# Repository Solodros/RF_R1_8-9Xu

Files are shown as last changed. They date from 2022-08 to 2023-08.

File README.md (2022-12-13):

# RF_R1_8-9Xu

Open source universal PCB for the Realforce R1 family of keyboards.

## Introduction

This project is a continuation of my development of open source EC boards.

The supported layouts are the one of the Realforce R1 family of keyboards, it being ANSI, ISO or JIS.

## Technical information

- Layout size: tenkeykess (TKL)
- Compatible switches: EC switches (Topre and NIZ)
- Microcontroller: STM32F401
- Connector:
    * internal USB-C
    * original JST connector S4B-EH(LF)(SN)
    * jst connector for daughterboard
- Addressable RGB strip support
- Firmware compatibility: QMK (with VIA/VIAL support)
- Protection hardware (on all connection methods):
  * Fused
  * ESD protection

## Renders and Prototypes

### Render

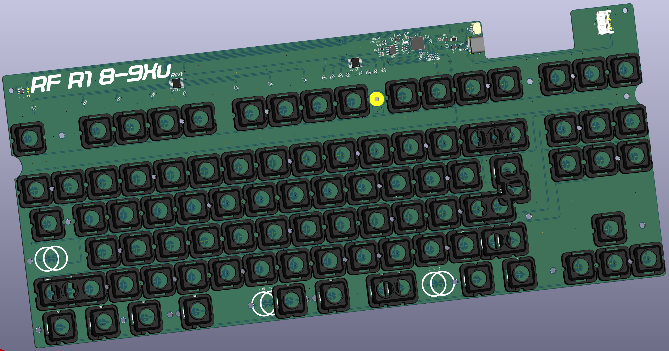
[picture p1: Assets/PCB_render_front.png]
PCB Front Render


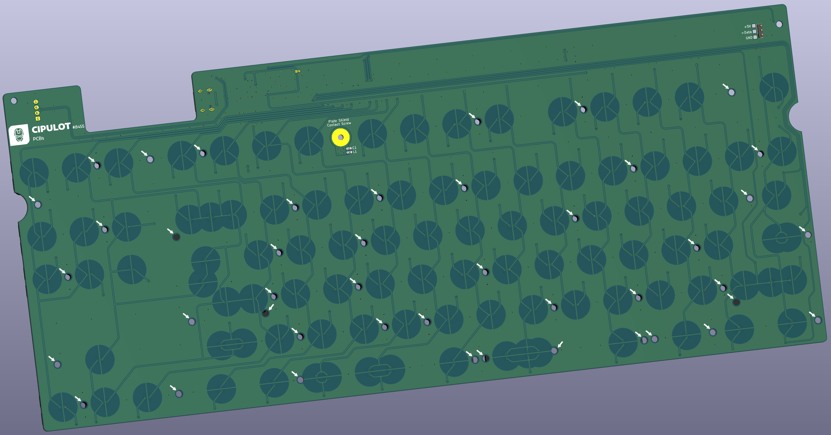
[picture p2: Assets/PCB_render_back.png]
PCB Back Render


### Prototype

PCB Front Proto

PCB Back Proto

## Revisions and relative features

### Rev1

This revision implements all the main features of the PCB.

#### Connectivity

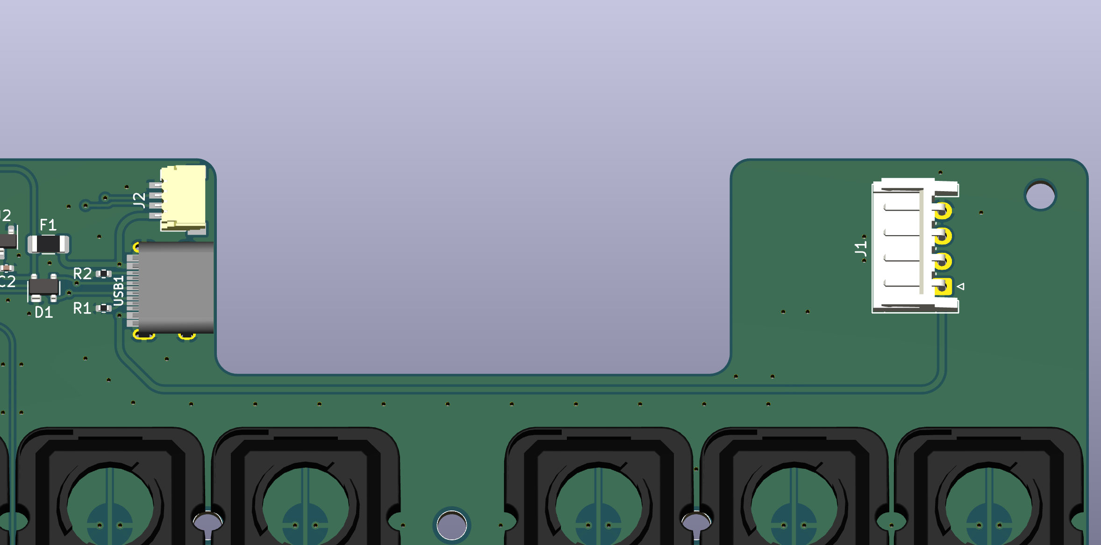
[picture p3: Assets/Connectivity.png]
Connectivity


Since this is first and foremost a replacement PCB for the original Realforce R1 PCB, the original JST connector is still supported. It's been moved to the right to accommodate the new JST connector for the daughterboard and the USB-C connector.

I thought about adding extra connectors so that if anyone wants to use this PCB in a custom project they can have the flexibility to use the connector that they prefer.

#### Addressable RGB strip support

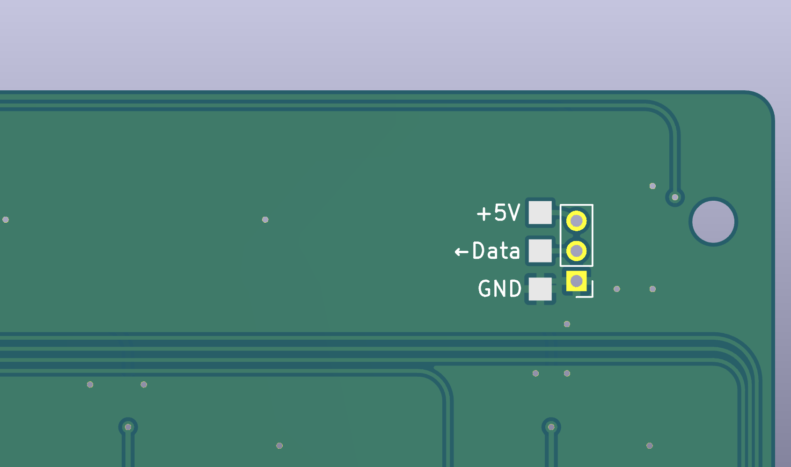
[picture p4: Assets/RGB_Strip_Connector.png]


Since the R1 PCB is used in some already existing custom PC (polycarbonate) cases, it was important to have a way to include a RGB strip support.

The strip can be directly sticked to the PCB and then wired to the PCB by soldering the pins to the THT pins or SMD pads.

Lighting can be controlled by the board itself and customization is achieved by using Vial/VIA.

### Rev 1.1

This revision implements the following changes:
  * added support for THT LED for Caps Lock and Scroll Lock
  * moved filtering components for plate shield to top side
  * added filtering components for USB-C shield
  * improved ground stitching

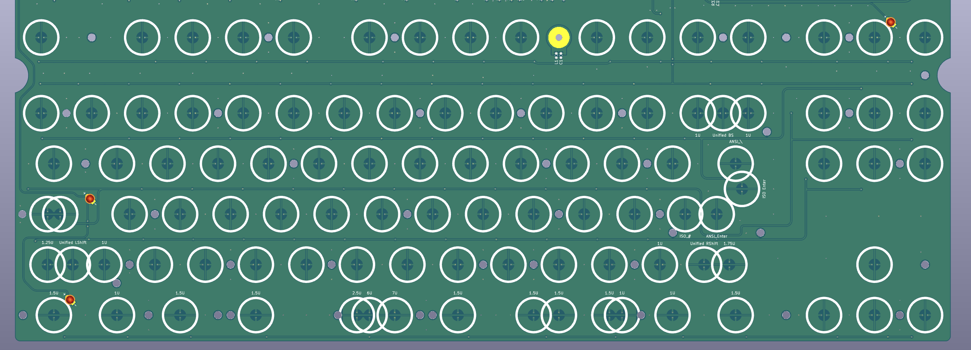
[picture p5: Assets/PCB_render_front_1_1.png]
PCB Front Render Rev 1.1


## "Why no plates?" I hear you say

It is what it is.

walky

For real though, the PCB is a replacement for the original Realforce R1 PCB so using the original plates is the preferred option. Furthermore, the multilayout support makes it tedious to make a plate design for each and every layout.

Nevertheless, if there's a particular plate config you want to use, you can always open an issue on the repository or even better make a PR from your own fork.

## Copyright notice

This project is released under the MIT License. For the license, please refer to the LICENSE.md file.

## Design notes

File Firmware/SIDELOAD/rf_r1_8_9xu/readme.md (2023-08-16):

# RF R1 8-9Xu

RF_R1_8-9Xu PCB

Open source universal PCB for the Realforce R1 family of keyboards.

* Keyboard Maintainer: [cipulot](https://github.com/cipulot)
* Hardware Supported: RF_R1_8-9Xu
* Hardware Availability: [Github](https://github.com/Cipulot/RF_R1_8-9Xu)

Make example for this keyboard (after setting up your build environment):

    make cipulot/rf_r1_8_9xu:default

Flashing example for this keyboard:

    make cipulot/rf_r1_8_9xu:default:flash

See the [build environment setup](https://docs.qmk.fm/#/getting_started_build_tools) and the [make instructions](https://docs.qmk.fm/#/getting_started_make_guide) for more information. Brand new to QMK? Start with our [Complete Newbs Guide](https://docs.qmk.fm/#/newbs).

## Bootloader

Enter the bootloader in 2 ways:

* **Physical Boot0 pins**: Short the Boot0 pins on the back of the PCB while plugging in the keyboard
* **Keycode in layout**: Press the key mapped to `QK_BOOT` if it is available

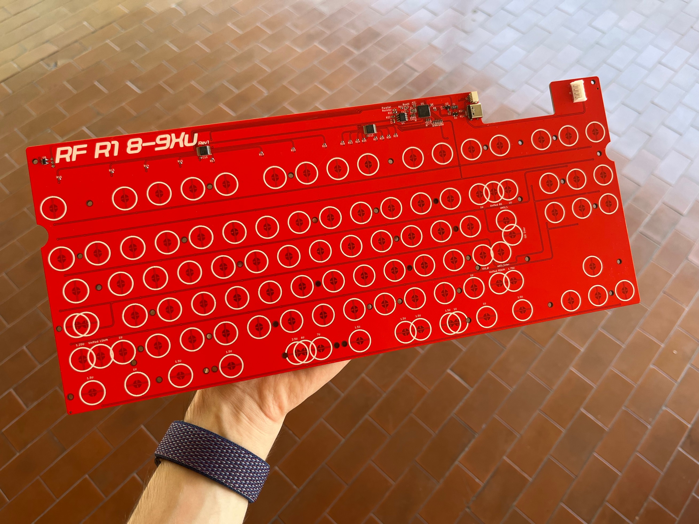
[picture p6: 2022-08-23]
Assets/PCB_proto_social.png

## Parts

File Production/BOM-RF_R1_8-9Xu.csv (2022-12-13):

Comment | Designator | Footprint | LCSC
JST | J1 | JST_EH_S4B-EH_1x04_P2.50mm_Horizontal | C265068
STM32F401CBUx | U1 | QFN-48-1EP_7x7mm_P0.5mm_EP5.6x5.6mm | C118825
OPA350 | U5 | SOIC-8_3.9x4.9mm_P1.27mm | C13388
JST | J2 | JST-SR-4 | C145956
100n | C1,C15 | C_0603_1608Metric | C14663
220p | C12 | C_0603_1608Metric | C1603
HRO-TYPE-C-31-M-12 | USB1 | HRO-TYPE-C-31-M-12-Assembly | C165948
1k | R22 | R_0603_1608Metric | C21190
330 | R33 | R_0603_1608Metric | C23138
4.7u | C2 | C_0402_1005Metric | C23733
100 | R3,R31,R32,R4,R6,R7,R8,R9 | R_0402_1005Metric | C25076
100k | R13,R14,R15,R16,R17,R18,R19,R20,R23,R24,R25,R26,R27,R28,R29,R30,R5 | R_0402_1005Metric | C25741
10k | R10,R11,R12 | R_0402_1005Metric | C25744
100k | R21 | R_0603_1608Metric | C25803
5.1k | R1,R2 | R_0402_1005Metric | C25905
PRTR5V0U2X | D1 | SOT-143 | C2827688
100n | C11,C13,C14,C5,C6,C7,C8,C9 | C_0402_1005Metric | C307331
ME6206A33M3G | U3 | SOT-23 | C35259
1u | C10,C3,C4 | C_0402_1005Metric | C52923
74HC4051 | U4,U6 | TSSOP16 | C5645
500mA | F1 | Fuse_1206_3216Metric | C70076
SN74AHCT1G125 | U2 | SOT-23-5 | C7484
220 @ 100MHz, 2A | L1 | L_0603_1608Metric | C85832
8 MHz | Y1 | Resonator_SMD_Murata_CSTxExxV-3Pin_3.0x1.1mm | C907975

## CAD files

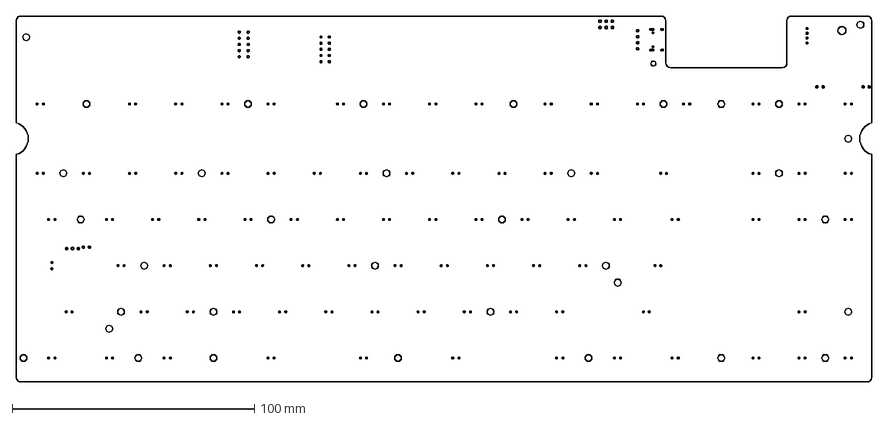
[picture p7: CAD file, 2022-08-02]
Assets/outline.dxf
353.0 x 151.0 mm

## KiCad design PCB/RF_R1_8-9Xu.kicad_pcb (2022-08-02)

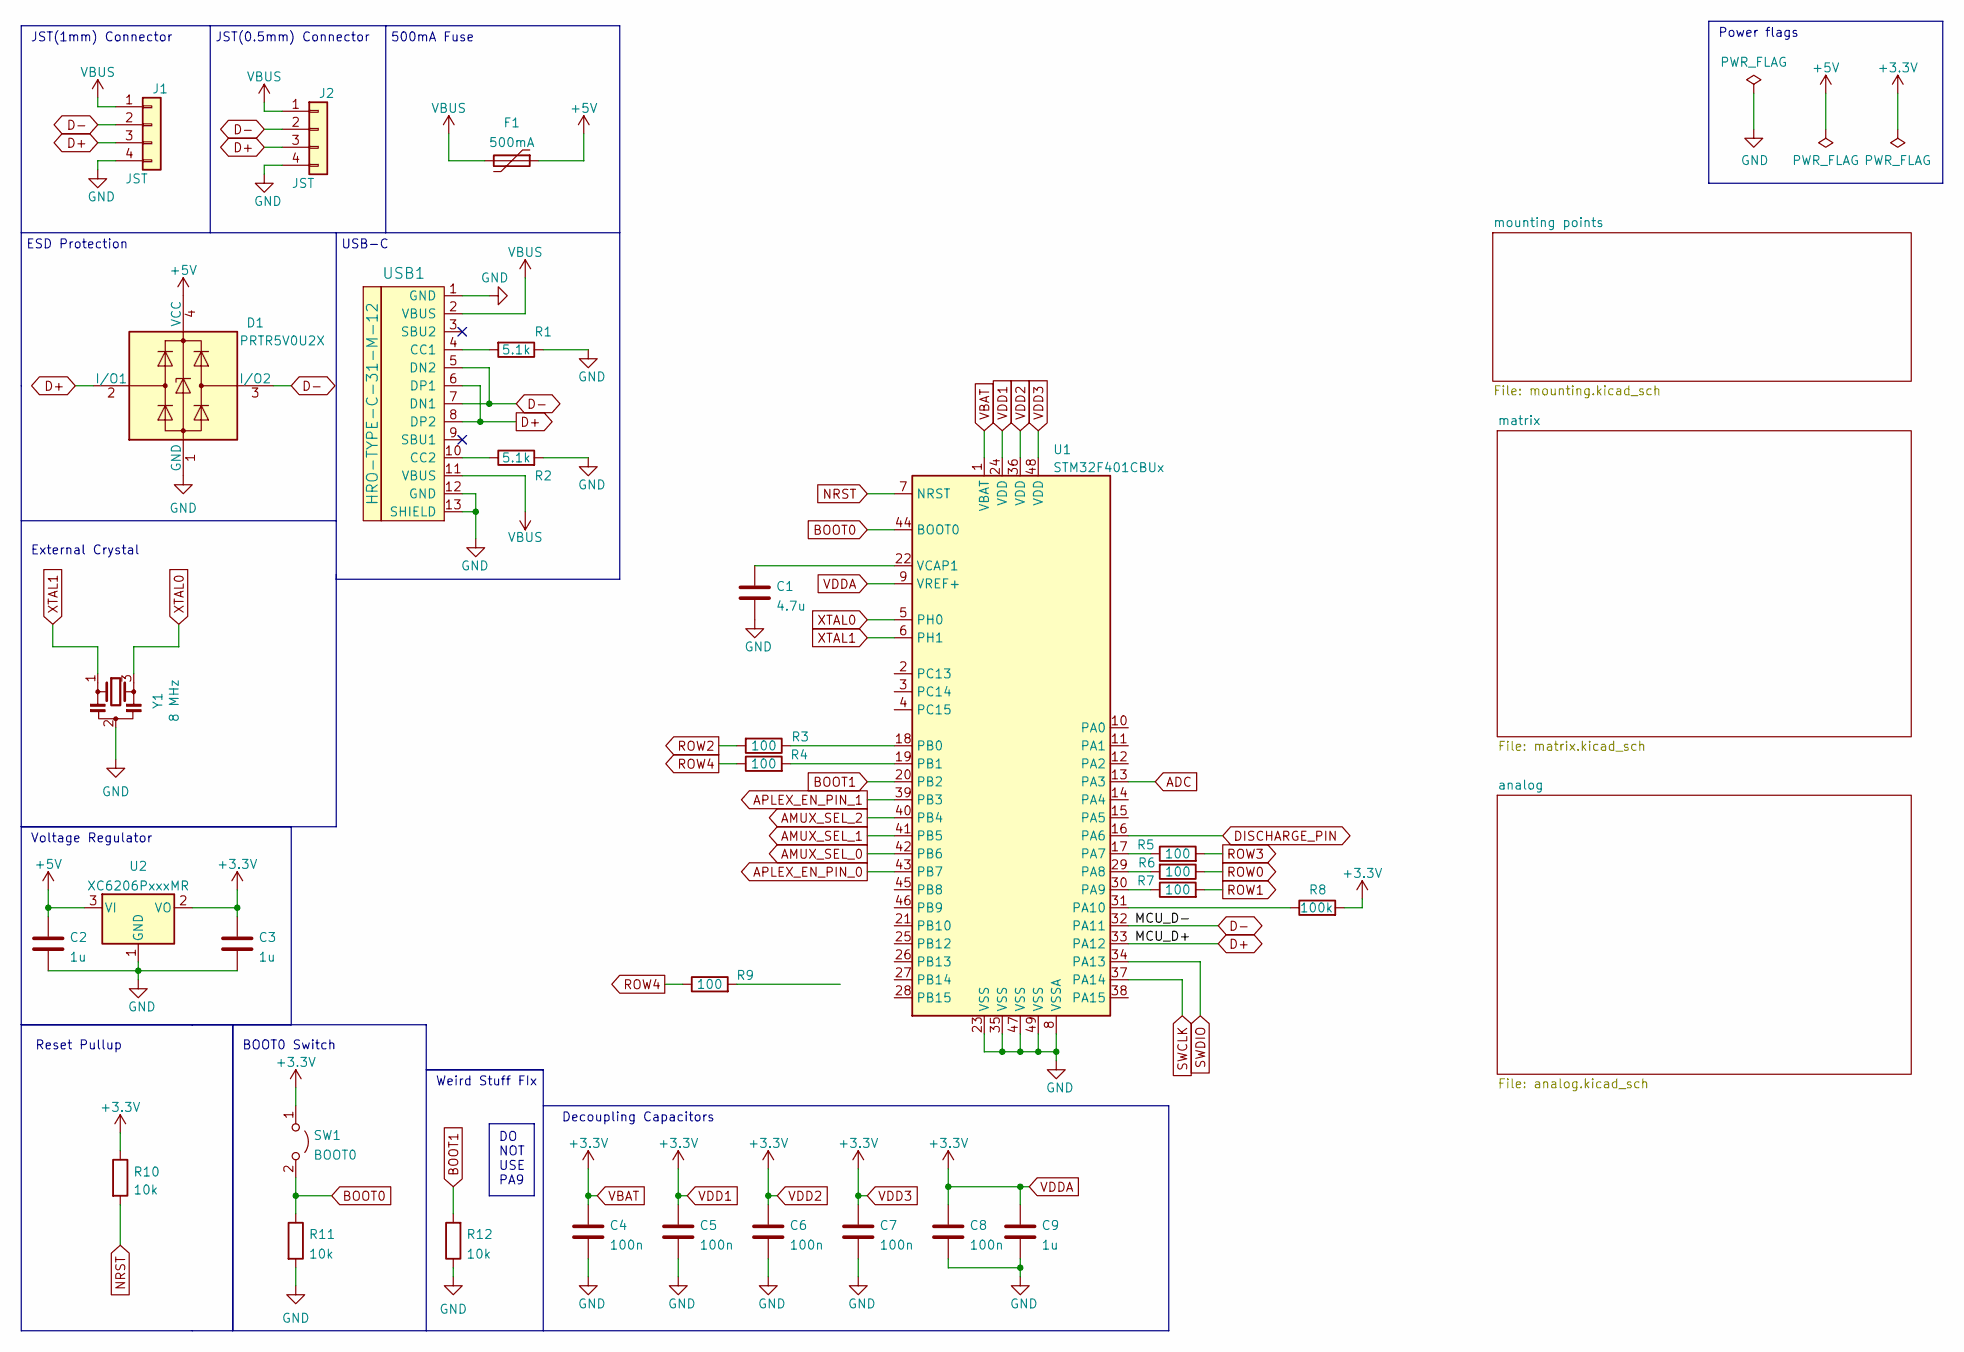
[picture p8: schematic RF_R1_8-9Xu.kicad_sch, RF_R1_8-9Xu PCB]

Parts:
C1: 4.7u; C_0402_1005Metric
C2, C3, C9: 1u; C_0402_1005Metric
C4, C5, C6, C7, C8: 100n; C_0402_1005Metric
D1: PRTR5V0U2X; SOT-143
F1: 500mA; Fuse_1206_3216Metric
J1: JST; JST_EH_S4B-EH_1x04_P2.50mm_Horizontal
J2: JST; JST-SR-4
R1, R2: 5.1k; R_0402_1005Metric
R3, R4, R5, R6, R7, R9: 100; R_0402_1005Metric
R8: 100k; R_0402_1005Metric
R10, R11, R12: 10k; R_0402_1005Metric
SW1: BOOT0; PinHeader_1x02_P2.54mm_Vertical
U1: STM32F401CBUx; QFN-48-1EP_7x7mm_P0.5mm_EP5.6x5.6mm
U2: XC6206PxxxMR; SOT-23
USB1: HRO-TYPE-C-31-M-12; HRO-TYPE-C-31-M-12-Assembly
Y1: 8 MHz; Resonator_SMD_Murata_CSTxExxV-3Pin_3.0x1.1mm; LCSC C907975

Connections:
+5V: C2.1, D1.4 (VCC), F1.1, U2.3 (VI)
ADC: U1.13 (PA3); also elsewhere on the board
AMUX_SEL_0: U1.42 (PB6); also elsewhere on the board
AMUX_SEL_1: U1.41 (PB5); also elsewhere on the board
AMUX_SEL_2: U1.40 (PB4); also elsewhere on the board
APLEX_EN_PIN_0: U1.43 (PB7); also elsewhere on the board
APLEX_EN_PIN_1: U1.39 (PB3); also elsewhere on the board
APLEX_OUT_PIN_0: U1.16 (PA6); also elsewhere on the board
BOOT0: R11.1, SW1.2 (B), U1.44 (BOOT0)
BOOT1: R12.2, U1.20 (PB2)
D+: D1.2 (I/O1), J1.3, J2.3, U1.33 (PA12), USB1.6 (DP1), USB1.8 (DP2)
D-: D1.3 (I/O2), J1.2, J2.2, U1.32 (PA11), USB1.5 (DN2), USB1.7 (DN1)
GND: C1.2, C2.2, C3.2, C4.2, C5.2, C6.2, C7.2, C8.2, C9.2, D1.1 (GND), J1.4, J2.4, R1.1, R2.2, R11.2, R12.1, U1.8 (VSSA), U1.23 (VSS), U1.35 (VSS), U1.47 (VSS), U1.49 (VSS), U2.1 (GND), USB1.1 (GND), USB1.12 (GND), USB1.13 (SHIELD), Y1.2; also elsewhere on the board
NRST: R10.2, U1.7 (NRST)
unnamed: C1.1, U1.22 (VCAP1)
unnamed: R1.2, USB1.4 (CC1)
unnamed: R2.1, USB1.10 (CC2)
unnamed: R3.1, U1.18 (PB0)
unnamed: R4.2, U1.19 (PB1)
unnamed: R5.1, U1.17 (PA7)
unnamed: R6.2, U1.29 (PA8)
unnamed: R7.1, U1.30 (PA9)
unnamed: R8.1, U1.31 (PA10)
ROW0: R6.1; also elsewhere on the board
ROW1: R7.2; also elsewhere on the board
ROW2: R3.2; also elsewhere on the board
ROW3: R5.2; also elsewhere on the board
ROW4: R4.1, R9.1; also elsewhere on the board
SWCLK: U1.37 (PA14)
SWDIO: U1.34 (PA13)
VBAT: C3.1, C4.1, C5.1, C6.1, C7.1, C8.1, C9.1, R8.2, R10.1, SW1.1 (A), U1.1 (VBAT), U1.9 (VREF+), U1.24 (VDD), U1.36 (VDD), U1.48 (VDD), U2.2 (VO); also elsewhere on the board
VBUS: F1.2, J1.1, J2.1, USB1.2 (VBUS), USB1.11 (VBUS)
XTAL0: U1.5 (PH0), Y1.3
XTAL1: U1.6 (PH1), Y1.1

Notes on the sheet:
DO NOT USE PA9
USB-C
Voltage Regulator
JST(1mm) Connector
JST(0.5mm) Connector
BOOT0 Switch
External Crystal
500mA Fuse
Weird Stuff FIx
Decoupling Capacitors
Power flags
ESD Protection
Reset Pullup

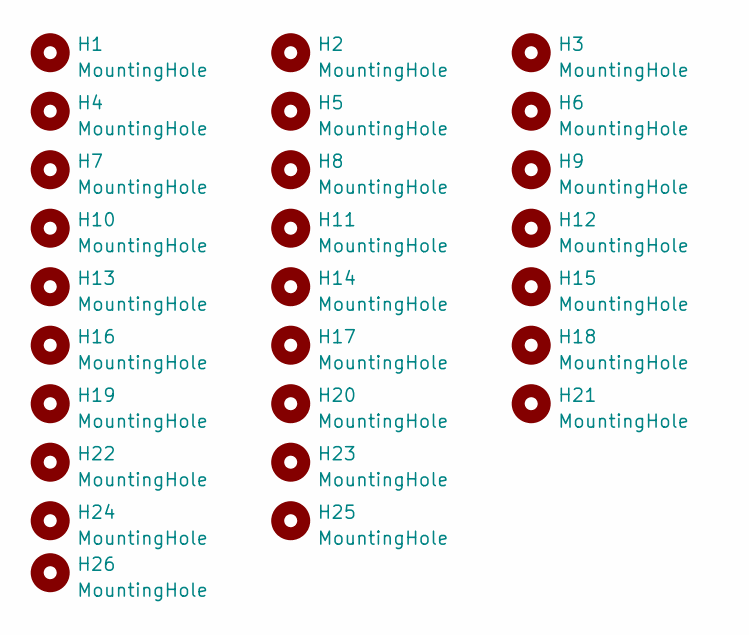
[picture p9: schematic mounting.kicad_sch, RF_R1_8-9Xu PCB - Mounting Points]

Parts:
H1, H2, H3, H4, H5, H6, H7, H8, H9, H10, H11, H12, H13, H14, H15, H16, H17, H18, H19, H20, H21, H22, H23, H24, H25, H26: MountingHole; HOLE_M2_RF

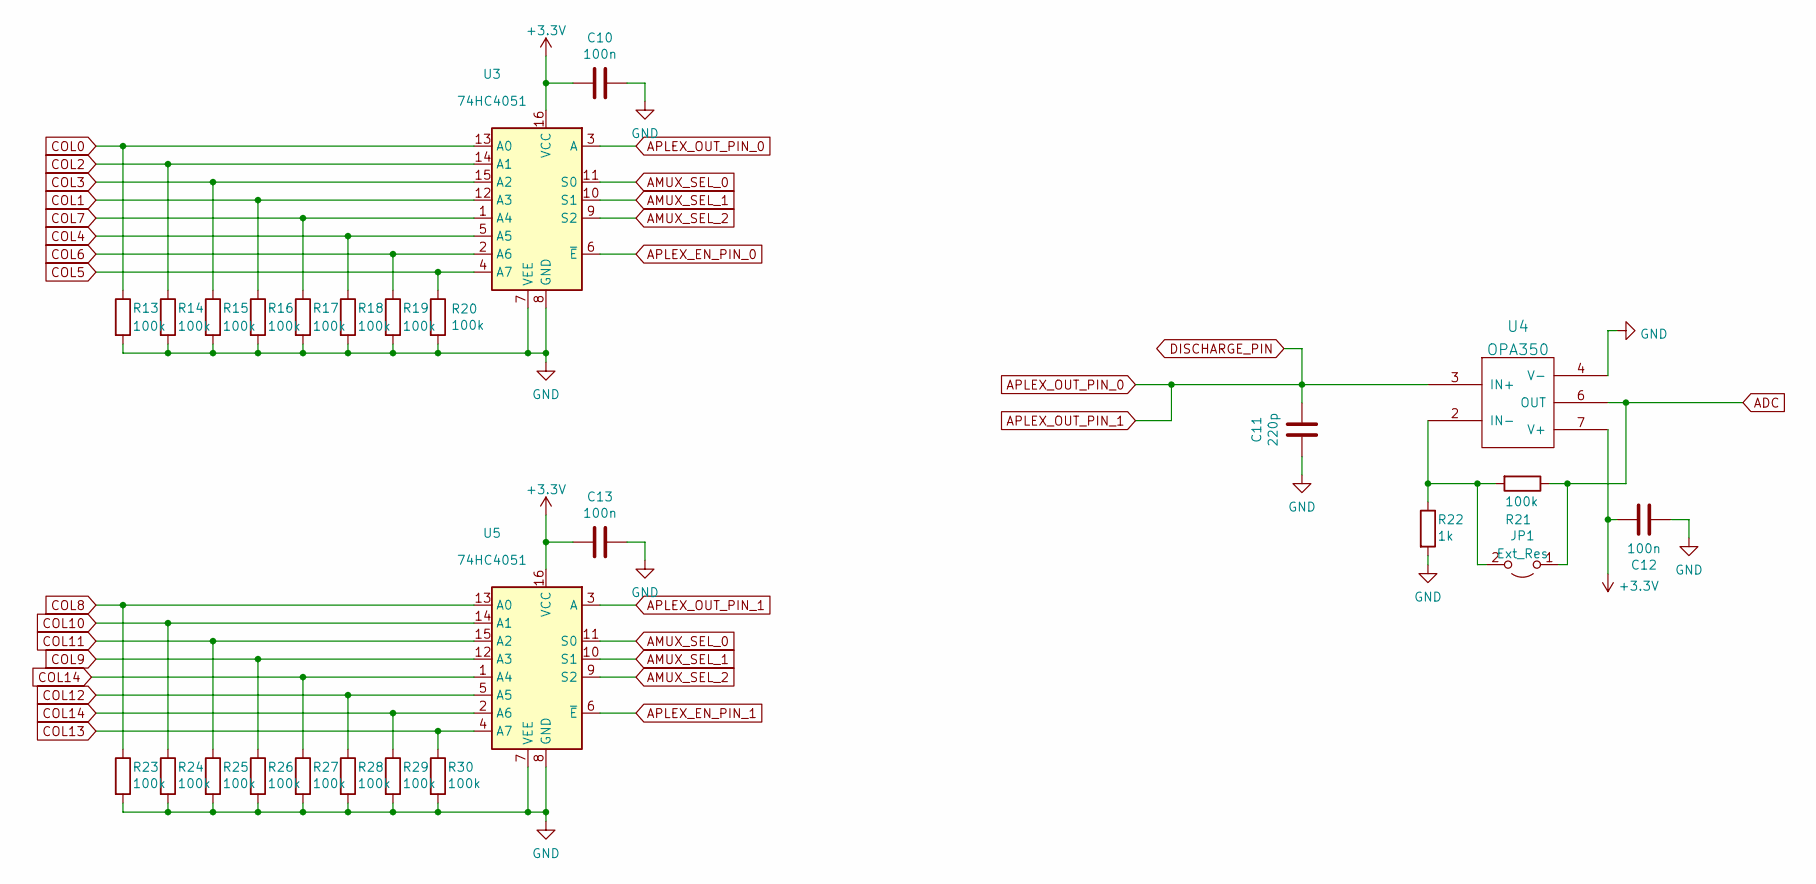
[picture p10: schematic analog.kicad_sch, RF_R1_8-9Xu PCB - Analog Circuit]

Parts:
C10, C12, C13: 100n; C_0402_1005Metric
C11: 220p; C_0402_1005Metric
JP1: Ext_Res; R_0603_1608Metric_Pad0.98x0.95mm_HandSolder
R13, R14, R15, R16, R17, R18, R19, R20, R21, R23, R24, R25, R26, R27, R28, R29, R30: 100k; R_0402_1005Metric
R22: 1k; R_0402_1005Metric
U3, U5: 74HC4051; TSSOP16
U4: OPA350; SOIC-8_3.9x4.9mm_P1.27mm

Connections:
ADC: JP1.1 (A), R21.1, U4.6 (OUT); also elsewhere on the board
AMUX_SEL_0: U3.11 (S0), U5.11 (S0); also elsewhere on the board
AMUX_SEL_1: U3.10 (S1), U5.10 (S1); also elsewhere on the board
AMUX_SEL_2: U3.9 (S2), U5.9 (S2); also elsewhere on the board
APLEX_EN_PIN_0: U3.6 (~E); also elsewhere on the board
APLEX_EN_PIN_1: U5.6 (~E); also elsewhere on the board
APLEX_OUT_PIN_0: C11.1, U3.3 (A), U4.3 (IN+), U5.3 (A); also elsewhere on the board
COL0: R13.1, U3.13 (A0); also elsewhere on the board
COL1: R16.1, U3.12 (A3); also elsewhere on the board
COL2: R14.1, U3.14 (A1); also elsewhere on the board
COL3: R15.1, U3.15 (A2); also elsewhere on the board
COL4: R18.1, U3.5 (A5); also elsewhere on the board
COL5: R20.1, U3.4 (A7); also elsewhere on the board
COL6: R19.1, U3.2 (A6); also elsewhere on the board
COL7: R17.1, U3.1 (A4); also elsewhere on the board
COL8: R23.1, U5.13 (A0); also elsewhere on the board
COL9: R26.1, U5.12 (A3); also elsewhere on the board
COL10: R24.1, U5.14 (A1); also elsewhere on the board
COL11: R25.1, U5.15 (A2); also elsewhere on the board
COL12: R28.1, U5.5 (A5); also elsewhere on the board
COL13: R30.1, U5.4 (A7); also elsewhere on the board
COL14: R27.1, R29.1, U5.1 (A4), U5.2 (A6); also elsewhere on the board
GND: C10.1, C11.2, C12.1, C13.1, R13.2, R14.2, R15.2, R16.2, R17.2, R18.2, R19.2, R20.2, R22.2, R23.2, R24.2, R25.2, R26.2, R27.2, R28.2, R29.2, R30.2, U3.7 (VEE), U3.8 (GND), U4.4 (V-), U5.7 (VEE), U5.8 (GND); also elsewhere on the board
unnamed: JP1.2 (B), R21.2, R22.1, U4.2 (IN-)
VBAT: C10.2, C12.2, C13.2, U3.16 (VCC), U4.7 (V+), U5.16 (VCC); also elsewhere on the board

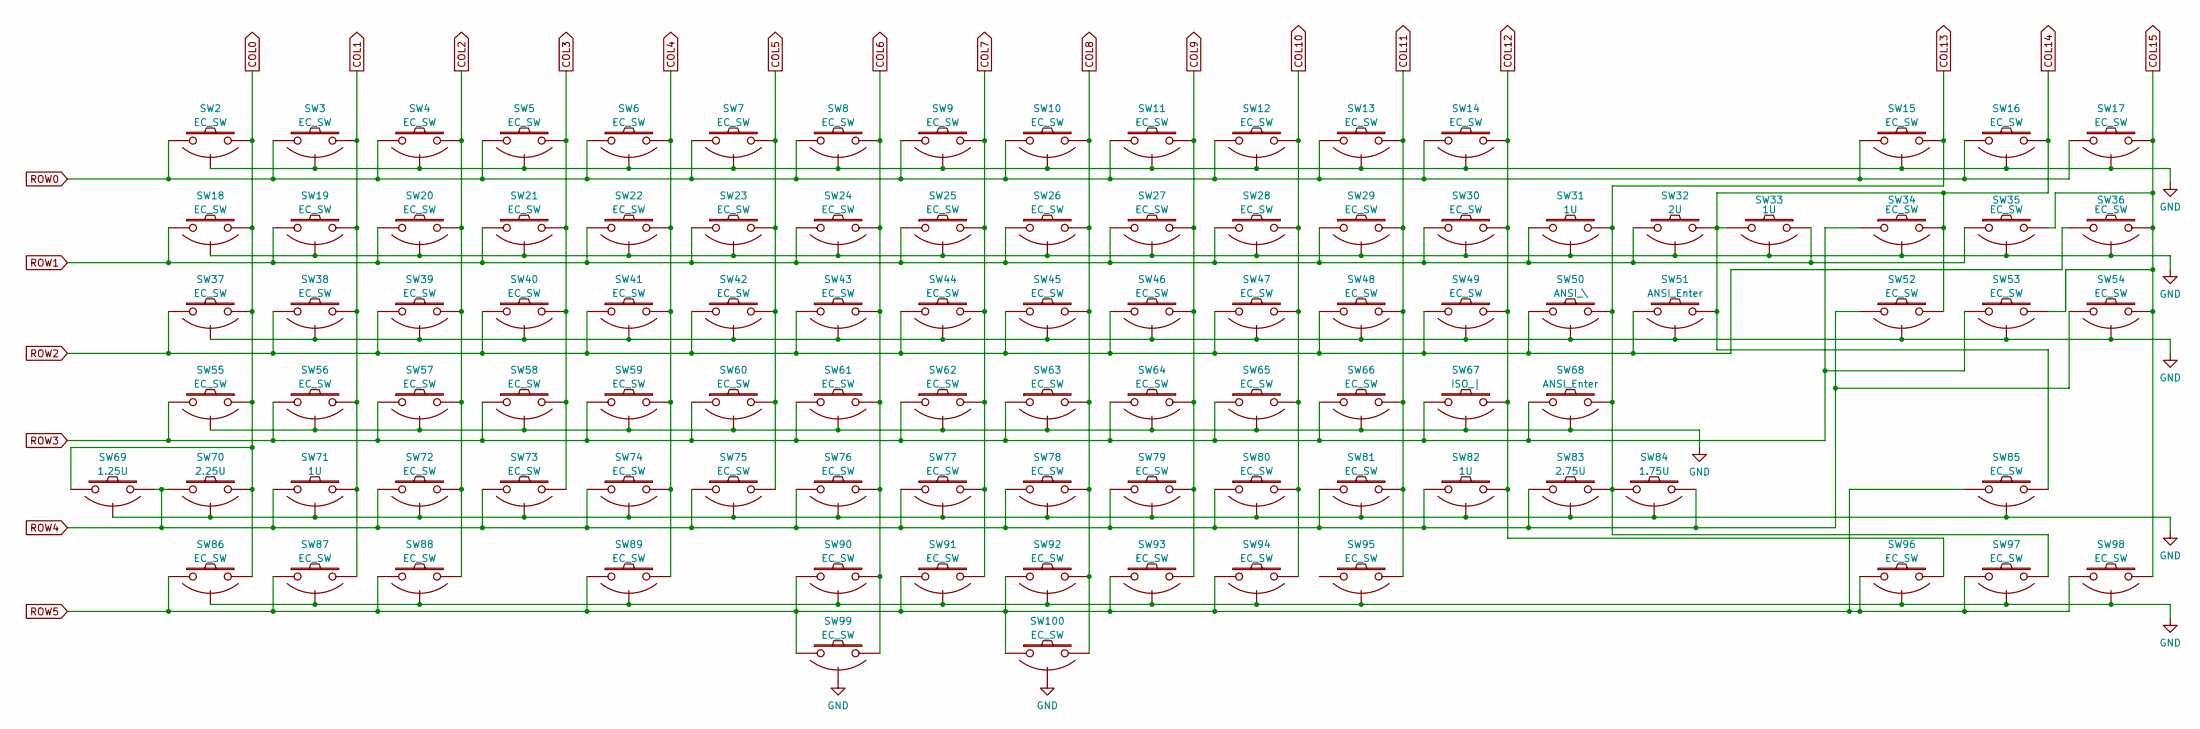
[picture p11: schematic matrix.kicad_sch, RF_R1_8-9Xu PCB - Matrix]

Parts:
SW2, SW3, SW4, SW5, SW6, SW7, SW8, SW9, SW10, SW11, SW12, SW13, SW14, SW15, SW16, SW17, SW18, SW19, SW20, SW21, SW22, SW23, SW24, SW25, SW26, SW27, SW28, SW29, SW30, SW34, SW35, SW36, SW37, SW38, SW39, SW40, SW41, SW42, SW43, SW44, SW45, SW46, SW47, SW48, SW49, SW52, SW53, SW54, SW56, SW57, SW58, SW59, SW60, SW61, SW62, SW63, SW64, SW65, SW66, SW72, SW73, SW74, SW75, SW76, SW77, SW78, SW79, SW80, SW81, SW85, SW86, SW87, SW88, SW89, SW91, SW92, SW94, SW95, SW96, SW97, SW98, SW99, SW100: EC_SW; ecs_pad_no_ring
SW31, SW33, SW82: 1U; ecs_pad_no_ring
SW32: 2U; ecs_pad_no_ring
SW50: ANSI_\; ecs_pad_no_ring
SW51, SW68: ANSI_Enter; ecs_pad_no_ring
SW55, SW90, SW93: EC_SW; ecs_pad_no_ring_stepped&normal
SW67: ISO_|; ecs_pad_no_ring
SW69: 1.25U; ecs_pad_no_ring
SW70: 2.25U; ecs_pad_no_ring_1u_edge_cut
SW71: 1U; ecs_pad_no_ring_1u_edge_cut
SW83: 2.75U; ecs_pad_no_ring
SW84: 1.75U; ecs_pad_no_ring

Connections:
COL0: SW2.2, SW18.2, SW37.2, SW55.1, SW69.2, SW70.1, SW86.2; also elsewhere on the board
COL1: SW3.2, SW19.2, SW38.2, SW56.2, SW71.2, SW87.2; also elsewhere on the board
COL2: SW4.2, SW20.2, SW39.2, SW57.2, SW72.2, SW88.2; also elsewhere on the board
COL3: SW5.2, SW21.2, SW40.2, SW58.2, SW73.2; also elsewhere on the board
COL4: SW6.2, SW22.2, SW41.2, SW59.2, SW74.2, SW89.2; also elsewhere on the board
COL5: SW7.2, SW23.2, SW42.2, SW60.2, SW75.2; also elsewhere on the board
COL6: SW8.2, SW24.2, SW43.2, SW61.2, SW76.2, SW90.2, SW99.2; also elsewhere on the board
COL7: SW9.2, SW25.2, SW44.2, SW62.2, SW77.2, SW91.2; also elsewhere on the board
COL8: SW10.2, SW26.2, SW45.2, SW63.2, SW78.2, SW92.2, SW100.2; also elsewhere on the board
COL9: SW11.2, SW27.2, SW46.2, SW64.2, SW79.2, SW93.2; also elsewhere on the board
COL10: SW12.2, SW28.2, SW47.2, SW65.2, SW80.2, SW94.2; also elsewhere on the board
COL11: SW13.2, SW29.2, SW48.2, SW66.2, SW81.2, SW95.2; also elsewhere on the board
COL12: SW14.2, SW30.2, SW49.2, SW67.2, SW82.2, SW96.2; also elsewhere on the board
COL13: SW15.2, SW31.2, SW50.2, SW68.2, SW83.2, SW84.2, SW97.2; also elsewhere on the board
COL14: SW16.2, SW32.2, SW33.2, SW34.2, SW51.2, SW52.2, SW85.2; also elsewhere on the board
COL15: SW17.2, SW35.2, SW36.2, SW53.2, SW54.2, SW98.2
GND: SW2.3 (SG), SW3.3 (SG), SW4.3 (SG), SW5.3 (SG), SW6.3 (SG), SW7.3 (SG), SW8.3 (SG), SW9.3 (SG), SW10.3 (SG), SW11.3 (SG), SW12.3 (SG), SW13.3 (SG), SW14.3 (SG), SW15.3 (SG), SW16.3 (SG), SW17.3 (SG), SW18.3 (SG), SW19.3 (SG), SW20.3 (SG), SW21.3 (SG), SW22.3 (SG), SW23.3 (SG), SW24.3 (SG), SW25.3 (SG), SW26.3 (SG), SW27.3 (SG), SW28.3 (SG), SW29.3 (SG), SW30.3 (SG), SW31.3 (SG), SW32.3 (SG), SW33.3 (SG), SW34.3 (SG), SW35.3 (SG), SW36.3 (SG), SW37.3 (SG), SW38.3 (SG), SW39.3 (SG), SW40.3 (SG), SW41.3 (SG), SW42.3 (SG), SW43.3 (SG), SW44.3 (SG), SW45.3 (SG), SW46.3 (SG), SW47.3 (SG), SW48.3 (SG), SW49.3 (SG), SW50.3 (SG), SW51.3 (SG), SW52.3 (SG), SW53.3 (SG), SW54.3 (SG), SW55.3 (SG), SW56.3 (SG), SW57.3 (SG), SW58.3 (SG), SW59.3 (SG), SW60.3 (SG), SW61.3 (SG), SW62.3 (SG), SW63.3 (SG), SW64.3 (SG), SW65.3 (SG), SW66.3 (SG), SW67.3 (SG), SW68.3 (SG), SW69.3 (SG), SW70.3 (SG), SW71.3 (SG), SW72.3 (SG), SW73.3 (SG), SW74.3 (SG), SW75.3 (SG), SW76.3 (SG), SW77.3 (SG), SW78.3 (SG), SW79.3 (SG), SW80.3 (SG), SW81.3 (SG), SW82.3 (SG), SW83.3 (SG), SW84.3 (SG), SW85.3 (SG), SW86.3 (SG), SW87.3 (SG), SW88.3 (SG), SW89.3 (SG), SW90.3 (SG), SW91.3 (SG), SW92.3 (SG), SW93.3 (SG), SW94.3 (SG), SW95.3 (SG), SW96.3 (SG), SW97.3 (SG), SW98.3 (SG), SW99.3 (SG), SW100.3 (SG); also elsewhere on the board
ROW0: SW2.1, SW3.1, SW4.1, SW5.1, SW6.1, SW7.1, SW8.1, SW9.1, SW10.1, SW11.1, SW12.1, SW13.1, SW14.1, SW15.1, SW16.1, SW17.1; also elsewhere on the board
ROW1: SW18.1, SW19.1, SW20.1, SW21.1, SW22.1, SW23.1, SW24.1, SW25.1, SW26.1, SW27.1, SW28.1, SW29.1, SW30.1, SW31.1, SW32.1, SW33.1, SW35.1; also elsewhere on the board
ROW2: SW36.1, SW37.1, SW38.1, SW39.1, SW40.1, SW41.1, SW42.1, SW43.1, SW44.1, SW45.1, SW46.1, SW47.1, SW48.1, SW49.1, SW50.1, SW51.1; also elsewhere on the board
ROW3: SW34.1, SW53.1, SW55.2, SW56.1, SW57.1, SW58.1, SW59.1, SW60.1, SW61.1, SW62.1, SW63.1, SW64.1, SW65.1, SW66.1, SW67.1, SW68.1; also elsewhere on the board
ROW4: SW52.1, SW54.1, SW69.1, SW70.2, SW71.1, SW72.1, SW73.1, SW74.1, SW75.1, SW76.1, SW77.1, SW78.1, SW79.1, SW80.1, SW81.1, SW82.1, SW83.1, SW84.1; also elsewhere on the board
ROW5: SW85.1, SW86.1, SW87.1, SW88.1, SW89.1, SW90.1, SW91.1, SW92.1, SW93.1, SW94.1, SW96.1, SW97.1, SW98.1, SW99.1, SW100.1

Board: 4 copper layers, 181 parts (0 on the bottom side), 50 nets, no tracks yet.

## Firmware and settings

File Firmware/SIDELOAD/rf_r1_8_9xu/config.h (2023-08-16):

/* Copyright 2023 Cipulot
 *
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
 * You should have received a copy of the GNU General Public License
 * along with this program.  If not, see <http://www.gnu.org/licenses/>.
 */

#pragma once

#define MATRIX_ROWS 6
#define MATRIX_COLS 16

#define MATRIX_ROW_PINS \
    { B15, A8, B13, B12, B14, B0 }

#define AMUX_COUNT 2
#define AMUX_MAX_COLS_COUNT 8

#define AMUX_EN_PINS \
    { B7, A6 }

#define AMUX_SEL_PINS \
    { B4, B5, B6 }

#define AMUX_COL_CHANNELS_SIZES \
    { 8, 8 }

#define AMUX_0_COL_CHANNELS \
    { 3, 0, 1, 2, 4, 6, 7, 5 }

#define AMUX_1_COL_CHANNELS AMUX_0_COL_CHANNELS

#define AMUX_COL_CHANNELS AMUX_0_COL_CHANNELS, AMUX_1_COL_CHANNELS

#define DISCHARGE_PIN A4
#define ANALOG_PORT A3

#define DEFAULT_ACTUATION_MODE 0
#define DEFAULT_MODE_0_ACTUATION_LEVEL 550
#define DEFAULT_MODE_0_RELEASE_LEVEL 500
#define DEFAULT_MODE_1_INITIAL_DEADZONE_OFFSET DEFAULT_MODE_0_ACTUATION_LEVEL
#define DEFAULT_MODE_1_ACTUATION_SENSITIVITY 70
#define DEFAULT_MODE_1_RELEASE_SENSITIVITY 70
#define DEFAULT_EXTREMUM 1023
#define EXPECTED_NOISE_FLOOR 0
#define DEFAULT_NOISE_FLOOR_SAMPLING_COUNT 30
#define DEFAULT_BOTTOMING_READING 1023
#define DEFAULT_CALIBRATION_STARTER true

#define DISCHARGE_TIME 10

// #define DEBUG_MATRIX_SCAN_RATE
#define DYNAMIC_KEYMAP_LAYER_COUNT 3
#define EECONFIG_KB_DATA_SIZE 202

/* Mechanical locking support. Use KC_LCAP, KC_LNUM or KC_LSCR instead in keymap */
#define LOCKING_SUPPORT_ENABLE

/* Locking resynchronize hack */
#define LOCKING_RESYNC_ENABLE

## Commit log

2022-08-09 Update and pre-production output
    [BOM-RF_R1_8-9Xu.csv, RF_R1_8-9Xu.kicad_sch, analog.kicad_sch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]
2022-08-09 Update for new part
    [BOM-RF_R1_8-9Xu.csv]
2022-08-09 Schematic update
    [analog.kicad_sch]
2022-08-10 Final PCB Rev
    [BOM-RF_R1_8-9Xu.csv, RF_R1_8-9Xu.kicad_sch, analog.kicad_sch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]
2022-08-10 Fix PA9 being used
    [RF_R1_8-9Xu.kicad_sch]
2022-08-12 Production files update
    [BOM-RF_R1_8-9Xu.csv, RF_R1_8-9Xu.kicad_sch]
2022-08-27 Update of PCB
    Added shielding copper pad for plate electrical connection, along with EMI filtering through capacitor and inductor.
    [BOM-RF_R1_8-9Xu.csv, RF_R1_8-9Xu.kicad_sch, analog.kicad_sch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]
2022-12-13 Updated files for Rev 1.1
    Features added:
    - THT LED for Caps Lock and Scroll Lock
    - moved filtering components for plate shield to top side
    - added filtering components for USB-C shield
    Firmware updated accordingly too.
    [BOM-RF_R1_8-9Xu.csv, RF_R1_8-9Xu.kicad_sch, analog.kicad_sch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]
2023-01-01 Fix in label text
    [RF_R1_8-9Xu.kicad_sch, matrix.kicad_sch]
2023-01-09 Updated footprints and relative models
    [RF_R1_8-9Xu.kicad_sch, matrix.kicad_sch]
2023-08-16 Addition of new FW
    New Sideload firmware release that enables new features as:
    - Rapid Trigger (still WIP with bugs)
    - Calibration
    Compatible with previous revisions PCBs.
    [config.h]

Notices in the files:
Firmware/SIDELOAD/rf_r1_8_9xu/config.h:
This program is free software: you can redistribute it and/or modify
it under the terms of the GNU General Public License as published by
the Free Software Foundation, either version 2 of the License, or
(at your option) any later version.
